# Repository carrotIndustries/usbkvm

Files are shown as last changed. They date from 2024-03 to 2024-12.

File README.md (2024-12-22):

USBKVM
======

You know this? Your home server won't ping anymore and now you gotta 
get a monitor and a keyboard to fix it, but can't find anywhere to put 
them?

Introducing USBKVM, a matchbox-sized keyboard, video monitor and mouse 
that you can use from the comfort of the screen and input devices you 
already have. It's just like a KVM over IP console you may find in a server 
rack, but without the network in between.

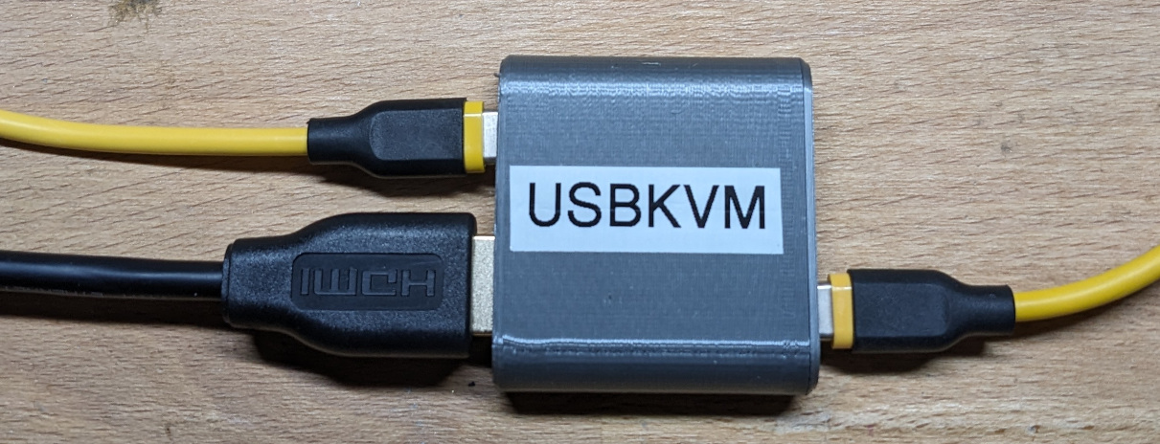
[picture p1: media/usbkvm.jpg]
A grey, obround 3D-printed 5x5 cm box with a white "USBKVM" label on it. A black HDMI cable an a yellow USB Type-C cable are connected on the left side. Another yellow USB Type-C cable is plugged into the right side.


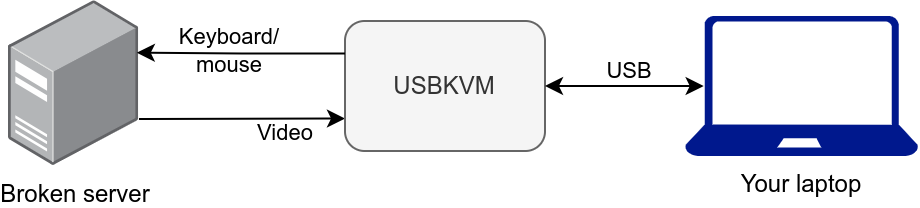
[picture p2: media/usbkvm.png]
Diagram showing a server connected to a laptop using USBKVM


# Quickstart

So you just your got your hands on a USBKVM and want to use it? See the app's [README](app/README.md) for how to install the client app.

# Hardware (USBKVM)

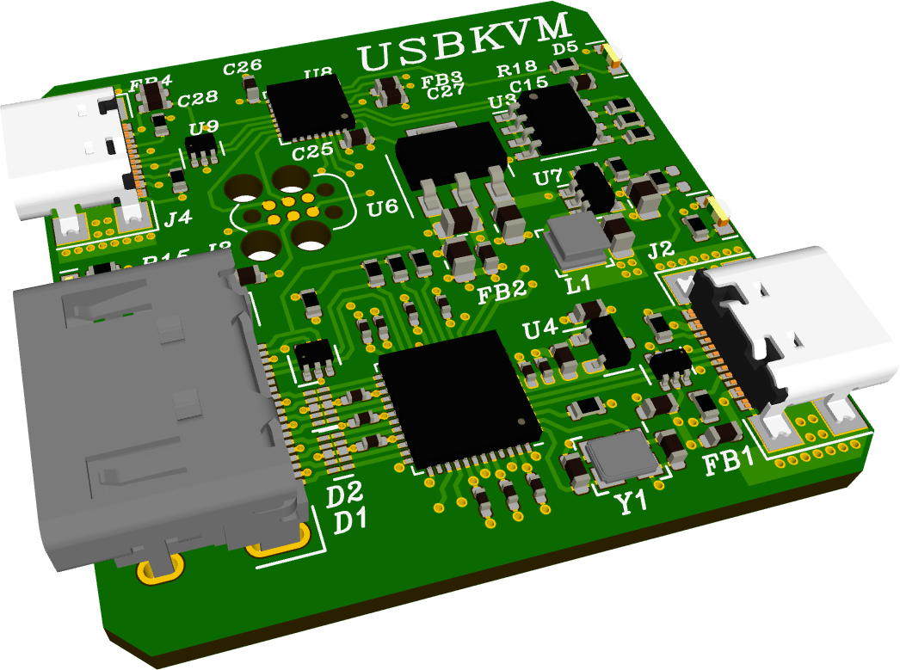
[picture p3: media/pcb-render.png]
3D rendering of a green PCA with an HDMI and a USB Type-C connector on the left edge. On the board itself, there are two QFN ICs as well as a variety of other components. On the right edge, there's another USB Type-C connector. USBKVM is silkscreend in the top right corner.


USBKVM is built around the MS2109 HDMI to USB capture IC that's found 
on virtually all cheap USB 2.0 HDMI capture sticks. It's not stocked by 
any of the usual distributors, I got mine from 
[klayers.net](https://www.klayers.net/product/ms2109/). They came with 
the [marking lasered 
off](https://chaos.social/@karotte/111456303962668464), which made me a bit suspicious that I've been 
scammed, but they work just like the original. So I either got the real 
deal or a perfect clone.

Turns out that this chip has an I²C controller builtin and people 
[reverse engineered](https://github.com/BertoldVdb/ms-tools/) to the 
point that it can be used to communicate with arbitrary I²C devices.

This I²C side channel is used to talk to an STM32F042 MCU that emulates 
USB keyboard and mouse.

Apart from these two chips, there's not much else on the board other 
than some voltage regulators, ESD protection diodes and an I²C EEPROM 
that holds configuration data for the MS2109.

The differential pairs for HDMI and USB are designed for JLCPCB's 7628 
stackup.

As usual, this board is made with [Horizon 
EDA](https://horizon-eda.org/). [Schematics](hw/usbkvm/output/schematic.pdf)

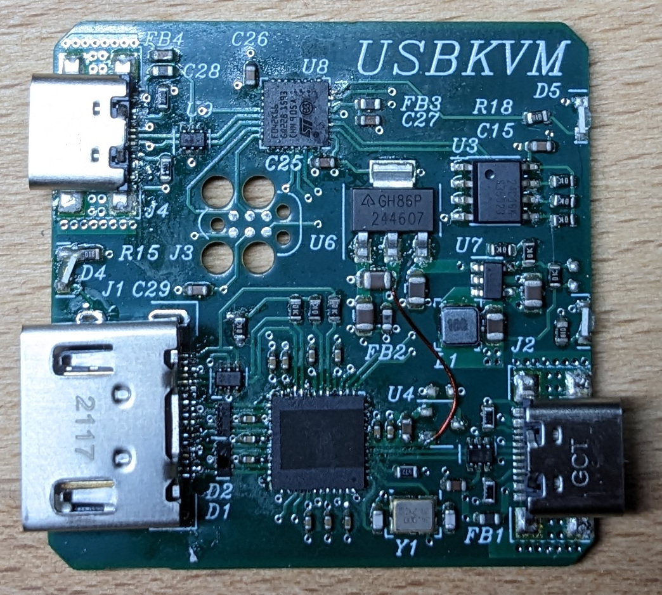
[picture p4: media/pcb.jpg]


The modwire is there because I forgot to order the voltage regulator 
for the 3.3V USB supply.

# Hardware (USBKVM Pro)

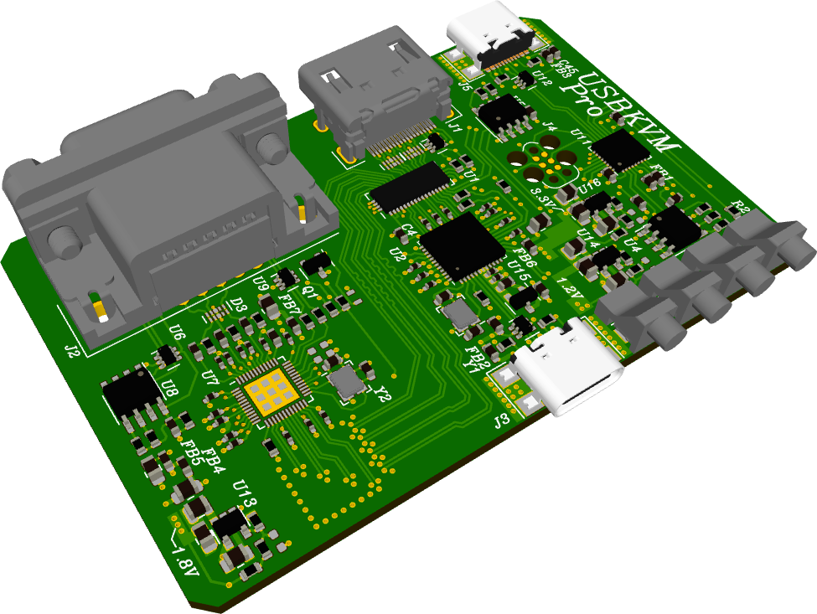
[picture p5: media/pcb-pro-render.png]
3D rendering of a green PCA with a VGA, HDMI and a USB Type-C connector on the left edge. On the board itself, there are thre QFN ICs as well as a variety of other components. On the right edge, there's another USB Type-C connector and four light pipes. USBKVM Pro is silkscreend in the top corner.


USBKVM Pro adds a VGA input since many servers still only provide VGA
video output. To accomplish this, the board includes the MS9288C VGA to 
HDMI converter and an HDMI mux to switch between HDMI and VGA input. 
Same as the MS2109, the MS9288C is available from 
[klayers.net](https://www.klayers.net/product/ms9288c/). The board has 
provision for connecting an I²C EEPROM to it, but so far I haven't 
found any documentation on how to make use of it. Anyhow, the chip 
works just fine without the EEPROM.

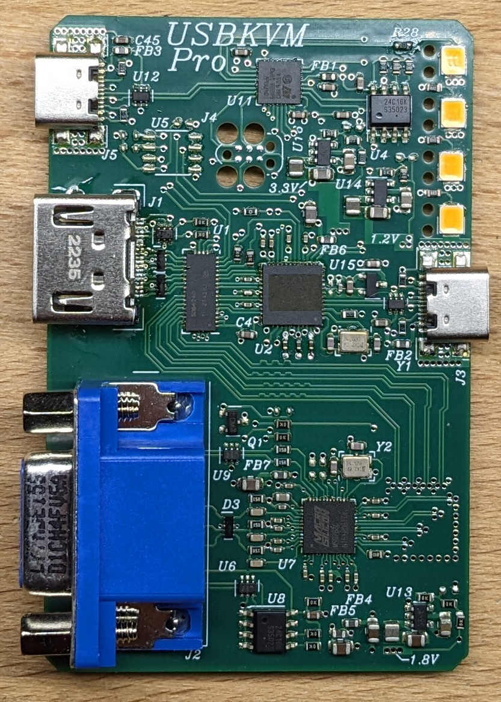
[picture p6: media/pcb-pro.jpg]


For automatically switching between HDMI and VGA input, the MCU senses 
the +5V applied to the VGA connector with an N-channel MOSFET. It's not 
directly connected to the MCU since it could reverse-power the MCU if 
host power isn't connected. For the same reason the I²C lines for the 
EDID EEPROM aren't connected to the MCU either.

USBKVM Pro uses warm white status LEDs since that's an indicator LED 
color I'd like to see more often among the sea of cold white and 
colored LEDs. Unfortunately though there are no decent warm white 
indicator LEDs, much less side view variants. So I went with LEDs 
intended for lighting applications running at much lower current and 
light pipes.

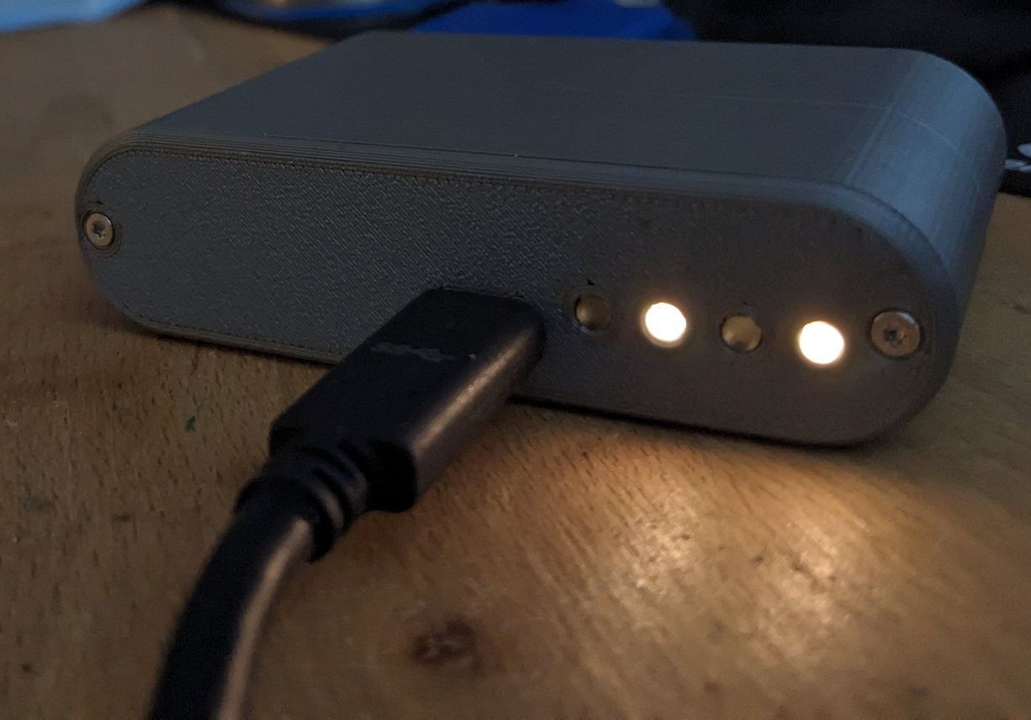
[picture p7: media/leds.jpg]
Warm white status LEDs reflecting on a wooden surface


# Programming

To be recognized by the client app and show color bars rather than a 
black screen for no input signal, the EEPROM attached to the MS2109 
needs to be programmed. This is done with the `cli` included in 
`ms-tools`: `./cli write-file EEPROM 0 progdata/ms2109.bin`. The EEPROM 
content is based on the one of a capture stick, modified with 
the "MS21XX&91XXDownloadTool_1.7.0" to set the device string to "USBKVM". 

For the Pro variant, there's also the VGA EDID EEPROM that requires 
programming. I cobbled together its contents by combining the EDID 
data from an LCD monitor with the one from the MS2109 using the [AW 
EDID 
Editor](https://www.analogway.com/emea/products/software-tools/aw-edid-editor/).
It's intended to be programmed using the VGA connector. To do so, load 
the `i2c-dev` kernel module and use the [converter 
script](progdata/convert-edid.py) to convert the EDID EEPROM 
[contents](progdata/edid.bin)
to a set of `i2ctransfer` commands. You probably need to adjust the I²C 
bus number to the right one for your system.

Apart from the firmware, the MCU needs the BOOT_SEL option bit cleared 
so that it can jump to the ROM bootloader. Unfortunately, openocd 
doesn't support this bit(?), so it has to be modified using the 
STM32Cube Programmer or via DFU.

# Software

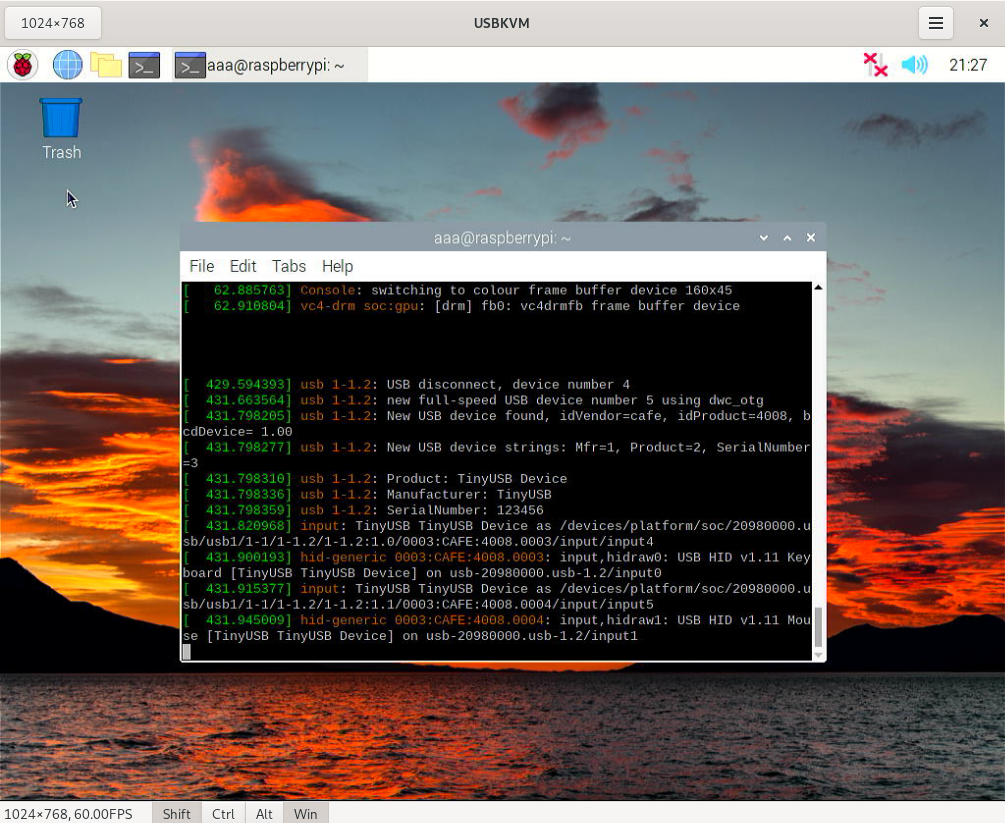
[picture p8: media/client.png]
The default Raspberry Pi OS desktop with a terminal window showing some dmesg output.


Conceptually, the client is pretty simple as it only has to do these 
two jobs:
 1. Display the captured video feed. The MS2109 implements the USB 
 video device class, just like a webcam.
 2. Send keyboard and mouse input the the MCU via the aforementioned I²C 
 interface

To get some video on the screen quickly, the client started out as a 
GStreamer Gtk example, first part done!

The second part however 
required some more work as the code that makes use of the MS2109's I²C 
interface is written in Go. After realizing that it's a surprisingly 
substantial amount code, I quickly scrapped the idea of reimplementing 
it in C++ and instead figured out how to compile it as a static library 
that I can integrate into my C++ project.

The protocol layer used for communicating with the MCU firmware is defined in 
a header file that's both included by the client an the firmware. Some 
care has to be taken to get the same struct packing on both platforms.

To keep the firmware simple, the client has to send USB HID scan codes, 
so it has to generate them from the key codes it receives from Gtk.
Not wanting to reinvent the wheel, I looked into the 
sources of software that has has to accomplish a similar task, in 
particular the [SPICE Gtk 
client](https://gitlab.freedesktop.org/spice/spice-gtk), and discovered 
the [keycodemap](https://gitlab.com/keycodemap/keycodemapdb) project. 
It provides a mapping table from the X11 keycodes used by Gtk to HID 
scancodes among some other codes used by different platforms.

Since I was too lazy to figure out how to properly capture the mouse to 
emit relative movements, USBKVM emulates an absolute pointing device. While this works perfectly 
on Windows and Linux, it's completely broken in less sophisticated 
environments such as UEFI setup utilities or option ROMs.

See the app's [README](app/README.md) for how to build it.

# Firmware

The firmware uses the excellent USB stack 
[tinyusb](https://github.com/hathach/tinyusb) to emulate the 
aforementioned absolute pointing devices as well as a standard USB HID 
keyboard. After having used the USB device stack included in the STM32 
HAL in some previous projects, I can't recommend tinyusb enough. It's 
really good as far as anything involving USB goes.

On the other end, it implements an I²C peripheral to receive commands 
from the MS2109. After some fiddling, I got it to work reliably 
without clock stretching since I don't think the MS2109 supports that. 
One side-effect of that is that the first byte the MCU has to send in a 
read transaction has to be loaded into the transmit data register even 
before the address is received since the time between the SCL edge that 
latches the last address bit and the first edge that clocks out the 
first data bye isn't long enough to prepare the data to be sent.

USBKVM and USBKVM Pro hardware variants are supported by one single 
firmware image. To tell them apart, pin PB8 is grounded on USBKVM Pro 
and floating on USBKVM.

## Firmware updates

TL;DR: Don't worry about it, the client app automatically does the right thing.

The first 8k of the 32kByte flash are reserved for the bootloader that can re-program the application image as directed via the I²C interface. The application image is prefixed by a header that contains its length and CRC checksum that the bootloader verifies before jumping to it. To make USBKVM brick-proof under normal usage, the bootloader doesn't immediately jump to the application on its own, but has to be told so by the client app. That way even an application image that passes the CRC check, but can't jump back to the bootloader doesn't result in a bricked USBKVM.

## Development

There are two firmware projects in the `fw/boot` and `fw/usbkvm` subdirectories. They share some code in `fw/common/`. Building them requires the usual arm-none-eabi toolchain, GNU make and python.

# Case

As usual, the case is of the 3D-printed kind. It consists of the 
obround main housing and a lid to close it up. The lid attaches with two M2 screws 
that go into nuts located in the main housing.

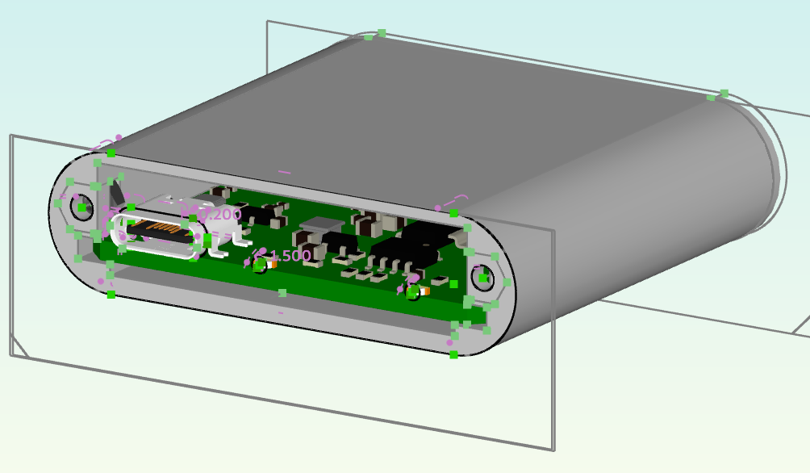
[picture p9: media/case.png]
Dune 3D screenshot of the case without the lid and some constraints visible.


The case was designed in [Dune 3D](https://dune3d.org/).

# Frequently asked questions

## Why doesn't this already exist?

Good question, given that at least
[three](https://news.ycombinator.com/item?id=39471860) 
[people](https://digipres.club/@foone/111948980229300662)
[independently](https://ioc.exchange/@azonenberg/110849751773610561)
asked the same thing. All of the key components 
are available off the shelf and USBKVM wasn't exactly hard to put 
together, 
so I guess it's mostly a question of time until someone else would have 
figured it out as well.

While writing this README, I stumbled upon 
[openinterface.com](https://openterface.com/) which appears to be 
pretty much the same thing as USBKVM. Zooming into [one of their PCB 
photos](https://twitter.com/TechxArtisan/status/1755577720568750462), 
they're also using the MS2109, what a coincidence! Looking at their 
subreddit they just went live less than two months ago.

## Why is this using such an obscure chip from a Chinese vendor?

I thought about how USBKVM would look like if I had to make it from 
parts I could get from Digikey. The best solution I could come up with 
would be using
a large MCU with camera input and High-Speed USB and then somehow 
connecting an HDMI to parallel RGB 
converter to its camera interface. While this could also have 
eliminated the MCU used for HID emulation, it's much more complex and 
expensive than the single QFN-48 IC that is the MS2109.

## How can I get one?

I have no plans to commercially offer USBKVM since I don't 
want to deal with the hurdles of manufacturing and selling hardware 
products.

If you're in the business of manufacturing and selling hardware, feel 
free to take the design files and turn USBKVM into a product people can 
buy! Just keep in mind that the firmware and client app are under GPL 
when making modifications to it.

## What platforms does the client run on?

Right now, the client app builds and runs on Linux. Windows support is 
experimental.

## Are there plans for clients for other platforms?

Right now, no. You're more than welcome to implement a client for your 
favourite platform based on the client included in this repo.

# Future improvements

While there's not much to improve on the hardware as it is right now, 
the client app still has a lot of room for improvement.

 - Make sure that it handles non-US keyboard layouts on both ends
 - Relative mouse emulation, requires firmware support
 - Screen recording, should be easy to add to the GStreamer pipeline
 - Instant replay to show screen content that just scrolled by
 - Key macros for repeatedly pressing keys
 - OCR for copying text from the video feed
 - Hardware mod: Wire up CEC from the HDMI connector to the MCU

# Licenses

 - Firmware and client: GPLv3
 - Hardware and Case: CERN Open Hardware Licence Version 2 - Permissive

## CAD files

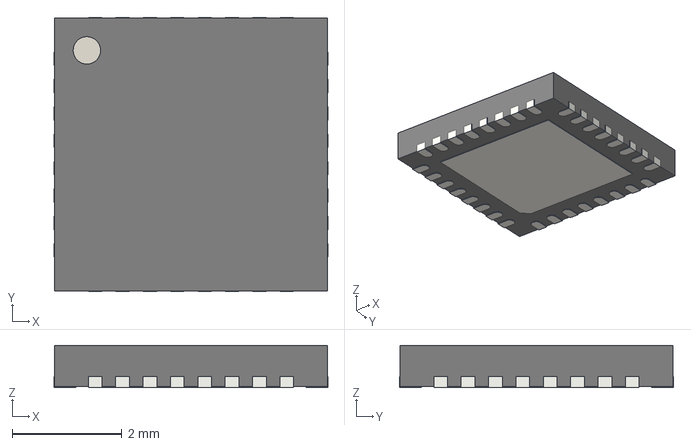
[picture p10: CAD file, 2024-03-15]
hw/usbkvm-pro/pool/3d_models/cache/6d752bc3-29b3-45df-8cf2-1e3aacefbcc6/3d_models/ic/qfn/QFN-32-1EP_5x5mm_P0.5mm.step
5.00 x 5.00 x 0.77 mm

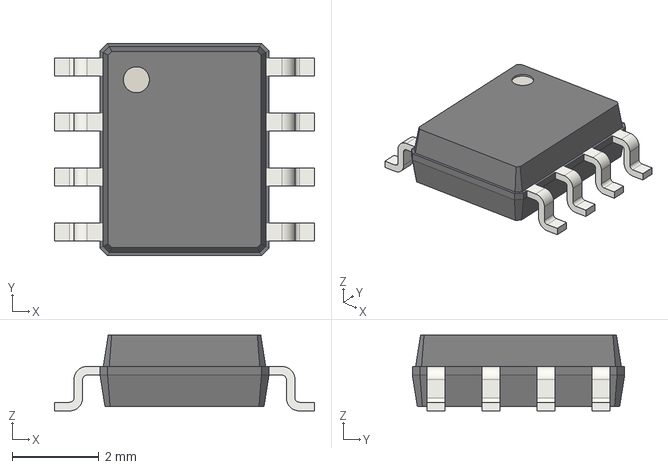
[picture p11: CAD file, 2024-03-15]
hw/usbkvm-pro/pool/3d_models/cache/6d752bc3-29b3-45df-8cf2-1e3aacefbcc6/3d_models/ic/so/SOIC-8_3.9x4.9mm_P1.27mm.step
6.00 x 4.90 x 1.75 mm

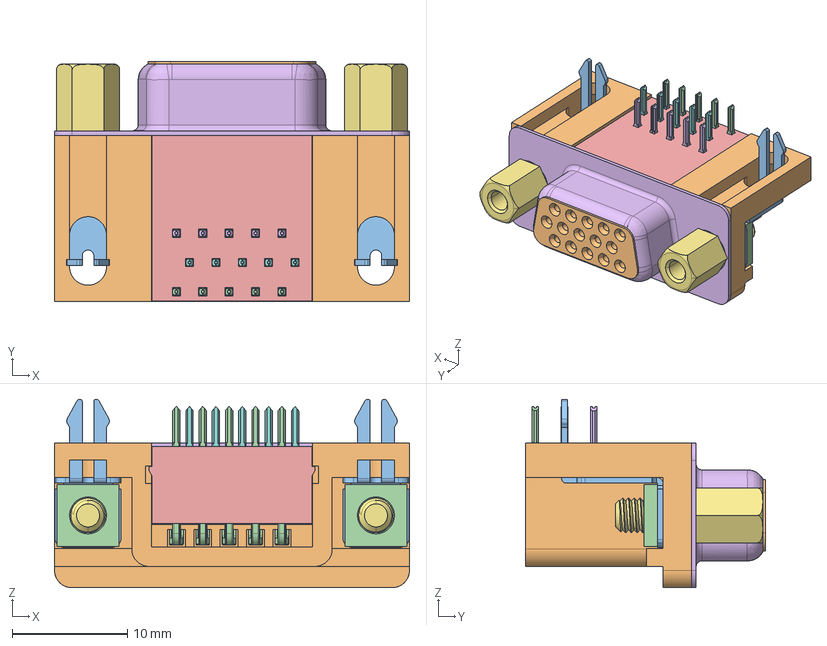
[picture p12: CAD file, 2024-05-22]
hw/usbkvm-pro/pool/3d_models/cache/6d752bc3-29b3-45df-8cf2-1e3aacefbcc6/3d_models/local/connectors/d-sub/L77HDE15SD1CH4FVGA--3DModel-STEP-533217.STEP
30.8 x 20.8 x 16.4 mm
D112-H15S_79
ZZ_11 x 2
MM_3 x 2
MANIFOLD_SOLID_BREP_13339 x 5
MANIFOLD_SOLID_BREP_16179 x 5
MANIFOLD_SOLID_BREP_18054
MANIFOLD_SOLID_BREP_20824
MANIFOLD_SOLID_BREP_22635
MANIFOLD_SOLID_BREP_25405
MANIFOLD_SOLID_BREP_27216
MANIFOLD_SOLID_BREP_29986
MANIFOLD_SOLID_BREP_31797
MANIFOLD_SOLID_BREP_34567
MANIFOLD_SOLID_BREP_37337
MANIFOLD_SOLID_BREP_39100
MANIFOLD_SOLID_BREP_40938 x 5
MANIFOLD_SOLID_BREP_43779 x 5
CC_25
H15S-SHEL_1
MM-2_1 x 2

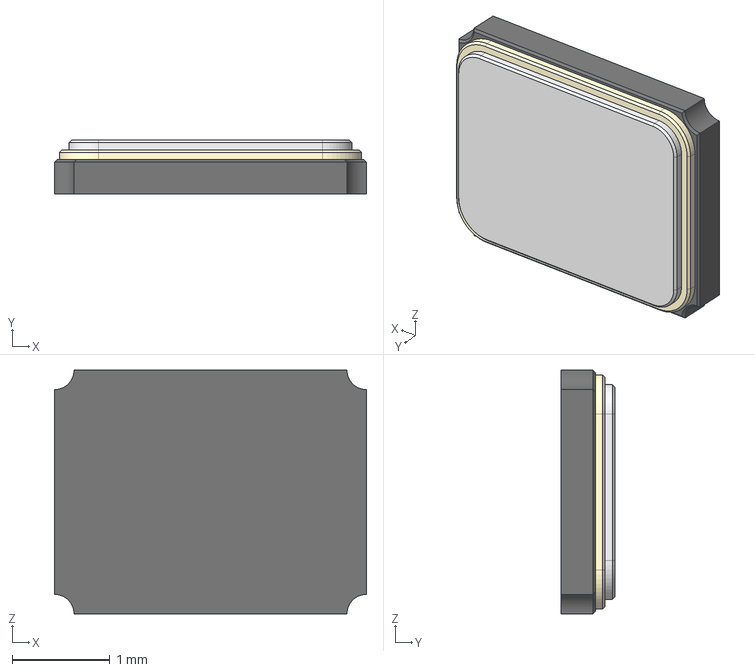
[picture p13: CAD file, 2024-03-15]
hw/usbkvm-pro/pool/3d_models/cache/6d752bc3-29b3-45df-8cf2-1e3aacefbcc6/3d_models/local/crystal/NX3225SA v2.step
3.20 x 0.55 x 2.50 mm

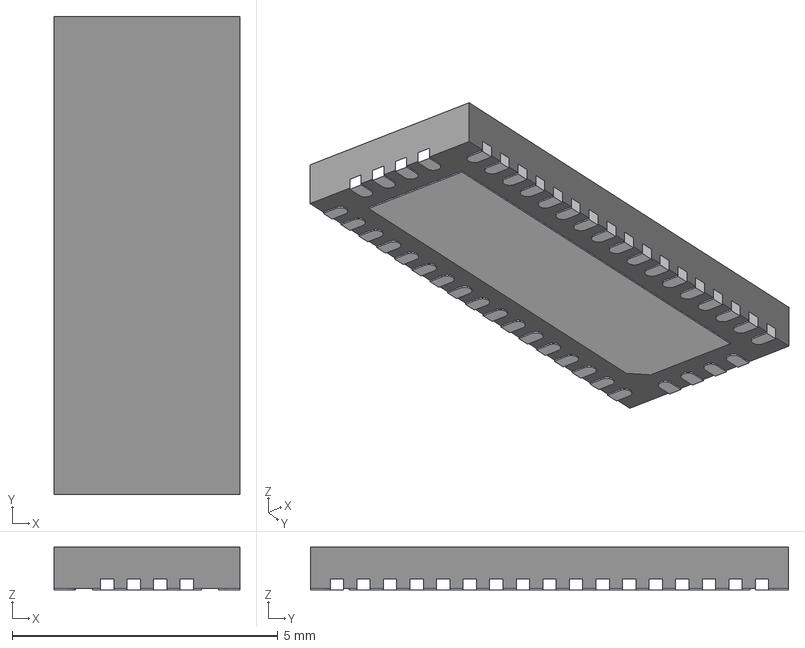
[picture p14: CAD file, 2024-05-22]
hw/usbkvm-pro/pool/3d_models/cache/6d752bc3-29b3-45df-8cf2-1e3aacefbcc6/3d_models/local/ic/ti/RUA0042A.stp
3.50 x 9.00 x 0.8 mm
FRAME

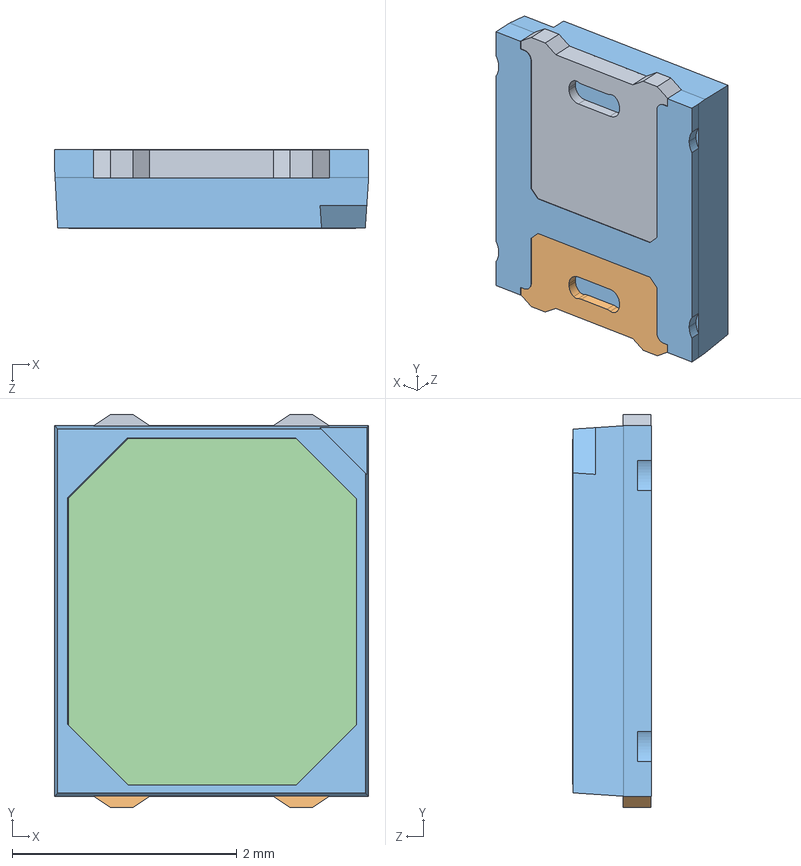
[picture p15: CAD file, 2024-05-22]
hw/usbkvm-pro/pool/3d_models/cache/6d752bc3-29b3-45df-8cf2-1e3aacefbcc6/3d_models/local/led/J Series 2835.STEP
2.80 x 3.50 x 0.706 mm
_____.STEP
_____-0.STEP
____.STEP

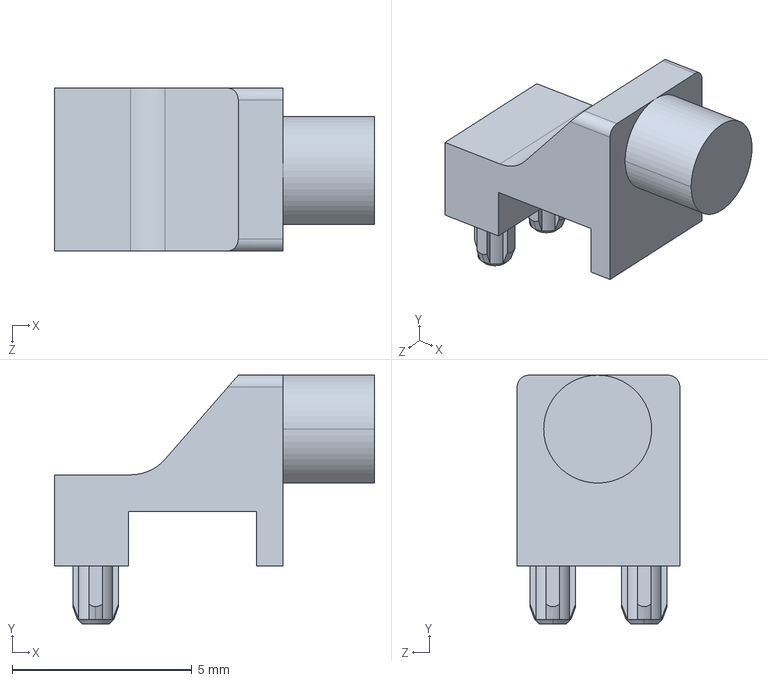
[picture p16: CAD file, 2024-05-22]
hw/usbkvm-pro/pool/3d_models/cache/6d752bc3-29b3-45df-8cf2-1e3aacefbcc6/3d_models/local/light-pipe/BIVAR__INC_SLP3-150-100-F.step
8.89 x 6.91 x 4.52 mm

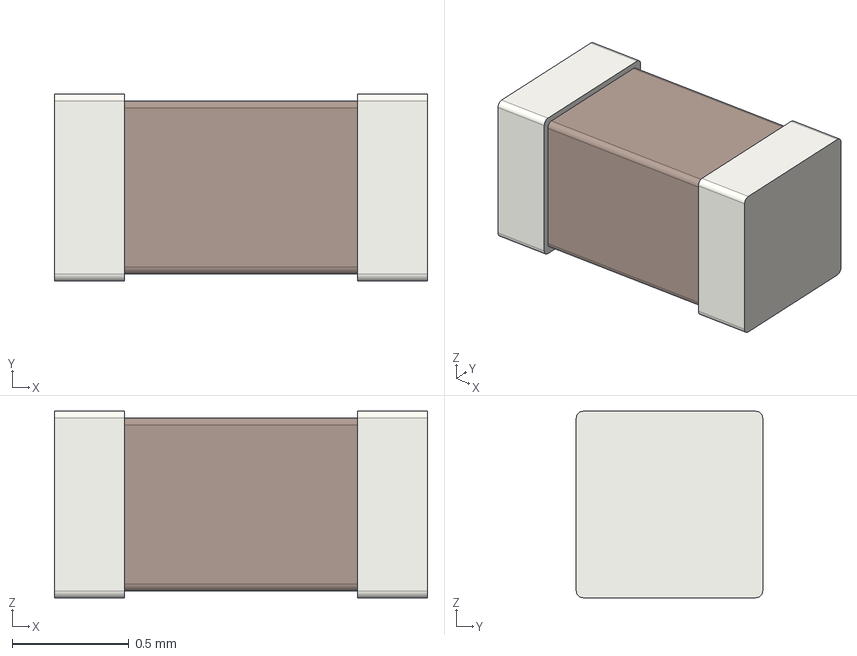
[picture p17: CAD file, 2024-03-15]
hw/usbkvm-pro/pool/3d_models/cache/6d752bc3-29b3-45df-8cf2-1e3aacefbcc6/3d_models/passive/capacitor/C_0603_1608Metric.step
1.60 x 0.8 x 0.8 mm

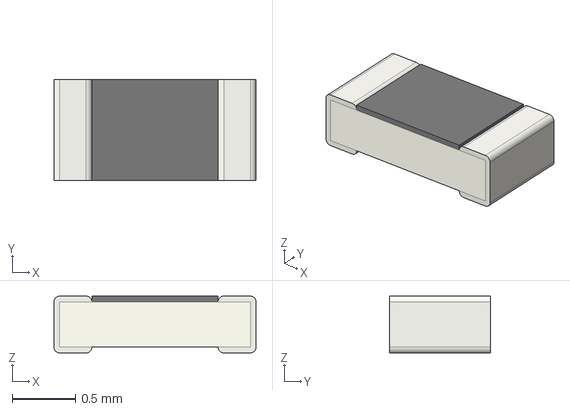
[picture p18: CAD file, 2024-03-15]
hw/usbkvm-pro/pool/3d_models/cache/6d752bc3-29b3-45df-8cf2-1e3aacefbcc6/3d_models/passive/resistor/R_0603_1608Metric.step
1.60 x 0.8 x 0.45 mm

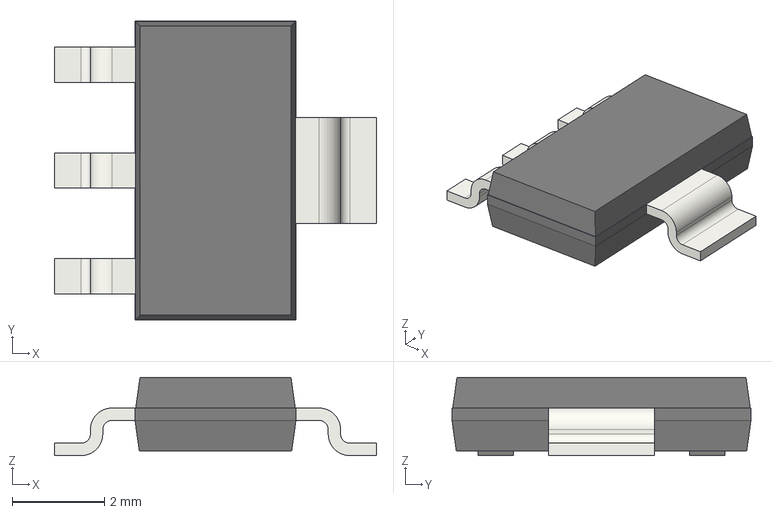
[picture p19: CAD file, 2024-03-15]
hw/usbkvm/pool/3d_models/cache/6d752bc3-29b3-45df-8cf2-1e3aacefbcc6/3d_models/ic/so/SOT-223.step
7.00 x 6.50 x 1.70 mm

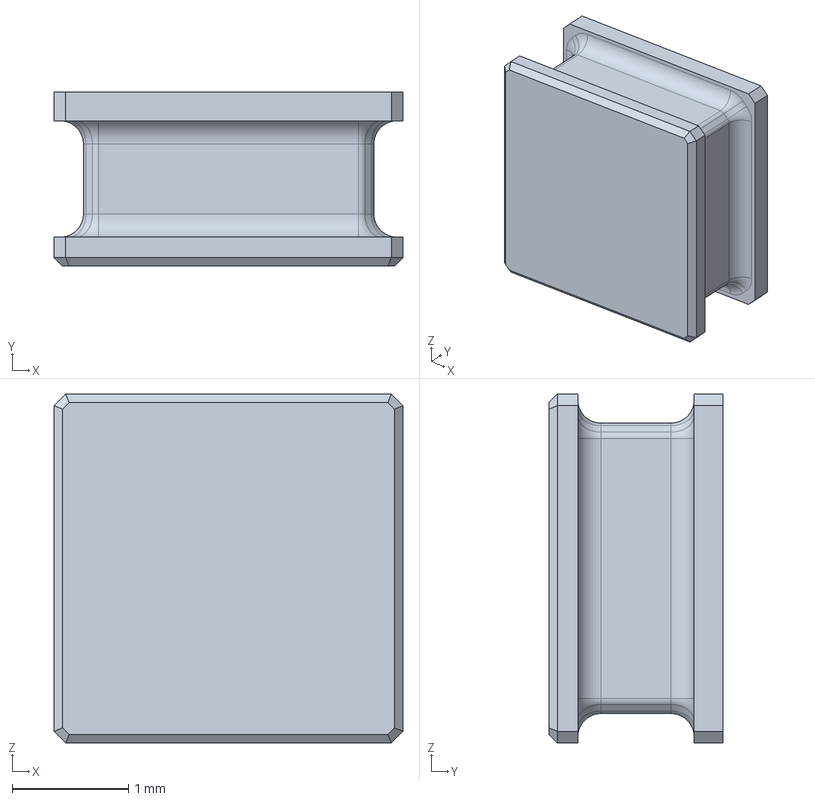
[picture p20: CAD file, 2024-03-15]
hw/usbkvm/pool/3d_models/cache/6d752bc3-29b3-45df-8cf2-1e3aacefbcc6/3d_models/local/inductors/Bourns-SRN3015.step
3.00 x 1.50 x 3.00 mm

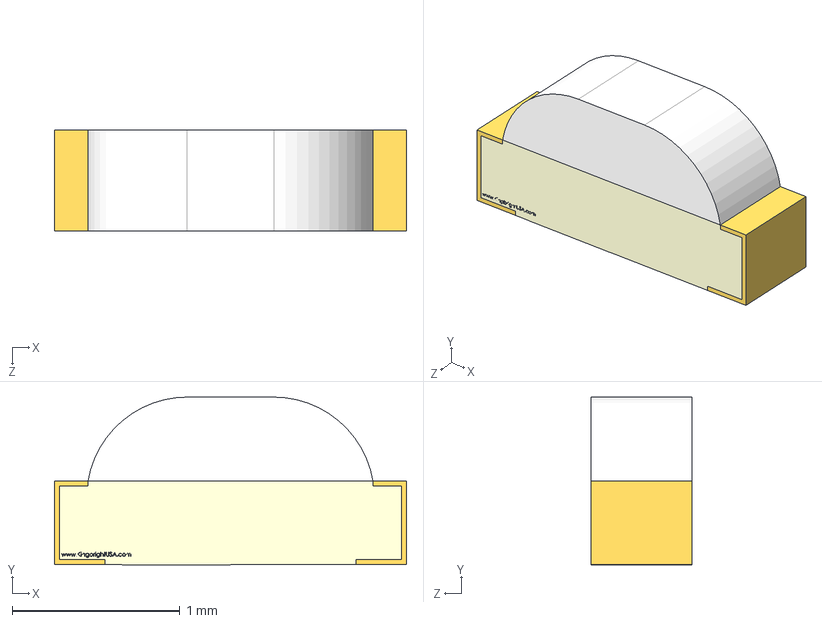
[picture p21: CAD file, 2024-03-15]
hw/usbkvm/pool/3d_models/cache/6d752bc3-29b3-45df-8cf2-1e3aacefbcc6/3d_models/local/led/APA2107.STEP
2.10 x 1.00 x 0.6 mm

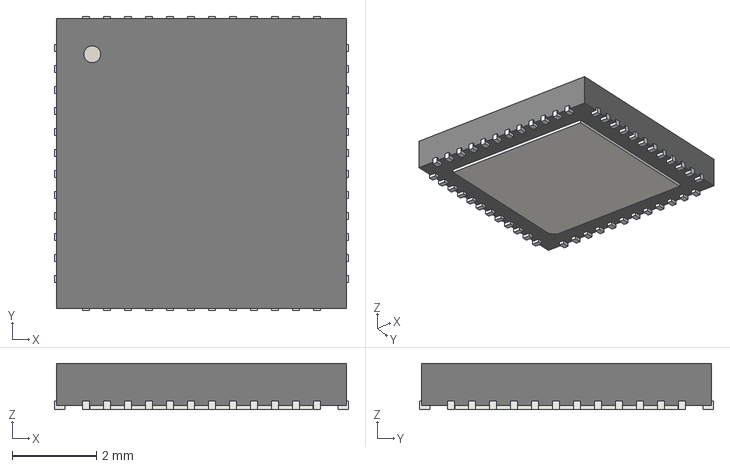
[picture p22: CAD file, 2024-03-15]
hw/usbkvm-pro/pool/3d_models/cache/6d752bc3-29b3-45df-8cf2-1e3aacefbcc6/3d_models/ic/qfn/QFN-48-1EP_7x7mm_P0.5mm_EP5.3x5.3mm.step
7.00 x 7.00 x 1.10 mm

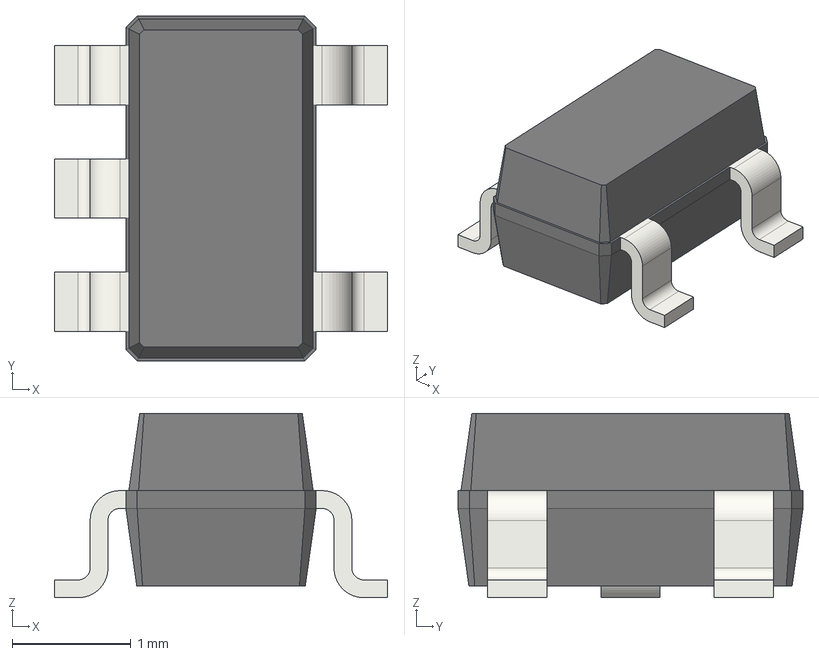
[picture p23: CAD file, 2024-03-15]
hw/usbkvm-pro/pool/3d_models/cache/6d752bc3-29b3-45df-8cf2-1e3aacefbcc6/3d_models/ic/so/SOT-23-5.step
2.80 x 2.90 x 1.55 mm

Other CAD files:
hw/usbkvm-pro/pool/3d_models/cache/6d752bc3-29b3-45df-8cf2-1e3aacefbcc6/3d_models/passive/capacitor/C_0402_1005Metric.step
hw/usbkvm-pro/pool/3d_models/cache/6d752bc3-29b3-45df-8cf2-1e3aacefbcc6/3d_models/ic/so/SOT-23.step
hw/usbkvm-pro/pool/3d_models/cache/6d752bc3-29b3-45df-8cf2-1e3aacefbcc6/3d_models/passive/capacitor/C_0805_2012Metric.step
hw/usbkvm-pro/pool/3d_models/cache/6d752bc3-29b3-45df-8cf2-1e3aacefbcc6/3d_models/ic/so/SOT-363_SC-70-6.step
hw/usbkvm-pro/pool/3d_models/cache/6d752bc3-29b3-45df-8cf2-1e3aacefbcc6/3d_models/local/connectors/hdmi/2086581051.stp
mech/90592A075_Steel Hex Nut.step

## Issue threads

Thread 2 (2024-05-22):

24Cxx EEPROM size and contents

G33KatWork, 2024-05-22:
Hi,

I want to build my own USBKVM. The BOM isn't clear on how big the 24Cxx EEPROM is supposed to be as the metadata in the Horizon project just says "24Cxx SOIC8" and not an exact part number. The part number isn't exactly readable either on the PCB image due to JPEG artifacts.

Also I guess it contains the firmware for the MS2109 that I need to dump from a USB/HDMI adapter and then write into the EEPROM? Or does the device work with just the ROM code as well?

carrotIndustries, 2024-05-22:
Will update the schematics in the coming days and add some flashing instructions.

It's a 16kBit eeprom and you need to program it with that file https://github.com/carrotIndustries/usbkvm/blob/main/hw/usbkvm/eep-usbkvm.bin using the cli from ms-tools: `cli  write-file EEPROM 0 eep-usbkvm.bin`

It's the EEPROM contents from the capture stick I ordered for testing, modified with the "MS21XX&91XXDownloadTool_1.7.0" to set the device string to "USBKVM". With the EEPROM contents I have it also shows color bars rather than a black screen when there's no input signal.

There's still a lot to be reverse-engineered about the MS2109.

G33KatWork, 2024-05-22:
Thanks!

I totally missed the bin file when looking around.

G33KatWork, 2024-06-02:
Okay, next question: Q1 in the USBKVM pro is again only a generic N-Channel MOSFET instead of an explicit part. Which one is it exactly?

carrotIndustries, 2024-06-02:
> Which one is it exactly?

2N7002, anything comparable will do.

> edit: And I assume the three (!) I2C EEPROM on the pro are all the same 16KBit EEPROMs?

The EEPROM for the MS9288C isn't required as I haven't found any info about what to put in it and the chip works fine without it.

For the VGA EDID eeprom, a 2kBit EEPROM would work as well, but I'm using a 16k one to keep the BOM shorter.

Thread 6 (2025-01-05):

mac OS Support

carrotIndustries, 2025-01-05:
So far, the USBKVM app only works on Linux and Windows. For mac OS support, at least these things need to be fixed:
 - Use the appropriate gstreamer source element
 - Figure out how to get the bus info from the video device
 - Figure out how to get the bus info from the HID device

The bus info is required to match up video and HID device.

JanKoppe, 2025-01-07:
Happy to play beta tester.

carrotIndustries, 2025-01-07:
A good start would be the output of `gst-device-monitor-1.0 -i Video/Source`  with a USBKVM attached.

iiidefix, 2025-01-13:
output of `gst-device-monitor-1.0 -i Video/Source` on macOS Sequoia 15.2 with gstreamer from Homebrew:
```
Device found:

        name  : USBKVM
        class : Video/Source
        caps  : video/x-raw(memory:GLMemory), width=1920, height=1080, format={ (string)UYVY, (string)YUY2 }, framerate={ (fraction)10/1, (fraction)20/1, (fraction)25/1, (fraction)3000003/100000, (fraction)750003/12500, (fraction)5/1 }, texture-target=rectangle
                video/x-raw(memory:GLMemory), width=1600, height=1200, format={ (string)UYVY, (string)YUY2 }, framerate={ (fraction)10/1, (fraction)20/1, (fraction)25/1, (fraction)3000003/100000, (fraction)750003/12500, (fraction)5/1 }, texture-target=rectangle
                video/x-raw(memory:GLMemory), width=1360, height=768, format={ (string)UYVY, (string)YUY2 }, framerate={ (fraction)10/1, (fraction)20/1, (fraction)25/1, (fraction)3000003/100000, (fraction)750003/12500, (fraction)8/1 }, texture-target=rectangle
                video/x-raw(memory:GLMemory), width=1280, height=1024, format={ (string)UYVY, (string)YUY2 }, framerate={ (fraction)10/1, (fraction)20/1, (fraction)25/1, (fraction)3000003/100000, (fraction)750003/12500, (fraction)8/1 }, texture-target=rectangle
                video/x-raw(memory:GLMemory), width=1280, height=960, format={ (string)UYVY, (string)YUY2 }, framerate={ (fraction)10/1, (fraction)20/1, (fraction)25/1, (fraction)3000003/100000, (fraction)750003/12500, (fraction)8/1 }, texture-target=rectangle
                video/x-raw(memory:GLMemory), width=1280, height=720, format={ (string)UYVY, (string)YUY2 }, framerate={ (fraction)20/1, (fraction)3000003/100000, (fraction)50/1, (fraction)750003/12500, (fraction)10/1 }, texture-target=rectangle
                video/x-raw(memory:GLMemory), width=1024, height=768, format={ (string)UYVY, (string)YUY2 }, framerate={ (fraction)20/1, (fraction)3000003/100000, (fraction)50/1, (fraction)750003/12500, (fraction)10/1 }, texture-target=rectangle
                video/x-raw(memory:GLMemory), width=800, height=600, format={ (string)UYVY, (string)YUY2 }, framerate={ (fraction)3000003/100000, (fraction)50/1, (fraction)750003/12500, (fraction)5/1, (fraction)10/1, (fraction)20/1 }, texture-target=rectangle
                video/x-raw(memory:GLMemory), width=720, height=576, format={ (string)UYVY, (string)YUY2 }, framerate={ (fraction)3000003/100000, (fraction)50/1, (fraction)750003/12500, (fraction)5/1, (fraction)10/1, (fraction)20/1, (fraction)25/1 }, texture-target=rectangle
                video/x-raw(memory:GLMemory), width=720, height=480, format={ (string)UYVY, (string)YUY2 }, framerate={ (fraction)5/1, (fraction)10/1, (fraction)20/1, (fraction)3000003/100000, (fraction)50/1, (fraction)750003/12500 }, texture-target=rectangle
                video/x-raw(memory:GLMemory), width=640, height=480, format={ (string)UYVY, (string)YUY2 }, framerate={ (fraction)5/1, (fraction)10/1, (fraction)20/1, (fraction)3000003/100000, (fraction)50/1, (fraction)750003/12500 }, texture-target=rectangle
                video/x-raw, width=1920, height=1080, format={ (string)UYVY, (string)YUY2, (string)NV12, (string)ARGB, (string)BGRA }, framerate={ (fraction)10/1, (fraction)20/1, (fraction)25/1, (fraction)3000003/100000, (fraction)750003/12500, (fraction)5/1 }
                video/x-raw, width=1600, height=1200, format={ (string)UYVY, (string)YUY2, (string)NV12, (string)ARGB, (string)BGRA }, framerate={ (fraction)10/1, (fraction)20/1, (fraction)25/1, (fraction)3000003/100000, (fraction)750003/12500, (fraction)5/1 }
                video/x-raw, width=1360, height=768, format={ (string)UYVY, (string)YUY2, (string)NV12, (string)ARGB, (string)BGRA }, framerate={ (fraction)10/1, (fraction)20/1, (fraction)25/1, (fraction)3000003/100000, (fraction)750003/12500, (fraction)8/1 }
                video/x-raw, width=1280, height=1024, format={ (string)UYVY, (string)YUY2, (string)NV12, (string)ARGB, (string)BGRA }, framerate={ (fraction)10/1, (fraction)20/1, (fraction)25/1, (fraction)3000003/100000, (fraction)750003/12500, (fraction)8/1 }
                video/x-raw, width=1280, height=960, format={ (string)UYVY, (string)YUY2, (string)NV12, (string)ARGB, (string)BGRA }, framerate={ (fraction)10/1, (fraction)20/1, (fraction)25/1, (fraction)3000003/100000, (fraction)750003/12500, (fraction)8/1 }
                video/x-raw, width=1280, height=720, format={ (string)UYVY, (string)YUY2, (string)NV12, (string)ARGB, (string)BGRA }, framerate={ (fraction)20/1, (fraction)3000003/100000, (fraction)50/1, (fraction)750003/12500, (fraction)10/1 }
                video/x-raw, width=1024, height=768, format={ (string)UYVY, (string)YUY2, (string)NV12, (string)ARGB, (string)BGRA }, framerate={ (fraction)20/1, (fraction)3000003/100000, (fraction)50/1, (fraction)750003/12500, (fraction)10/1 }
                video/x-raw, width=800, height=600, format={ (string)UYVY, (string)YUY2, (string)NV12, (string)ARGB, (string)BGRA }, framerate={ (fraction)3000003/100000, (fraction)50/1, (fraction)750003/12500, (fraction)5/1, (fraction)10/1, (fraction)20/1 }
                video/x-raw, width=720, height=576, format={ (string)UYVY, (string)YUY2, (string)NV12, (string)ARGB, (string)BGRA }, framerate={ (fraction)3000003/100000, (fraction)50/1, (fraction)750003/12500, (fraction)5/1, (fraction)10/1, (fraction)20/1, (fraction)25/1 }
                video/x-raw, width=720, height=480, format={ (string)UYVY, (string)YUY2, (string)NV12, (string)ARGB, (string)BGRA }, framerate={ (fraction)5/1, (fraction)10/1, (fraction)20/1, (fraction)3000003/100000, (fraction)50/1, (fraction)750003/12500 }
                video/x-raw, width=640, height=480, format={ (string)UYVY, (string)YUY2, (string)NV12, (string)ARGB, (string)BGRA }, framerate={ (fraction)5/1, (fraction)10/1, (fraction)20/1, (fraction)3000003/100000, (fraction)50/1, (fraction)750003/12500 }
        properties:
                device.api = avf
                avf.unique_id = 0x100000534d2109
                avf.model_id = UVC Camera VendorID_21325 ProductID_8457
                avf.has_flash = false
                avf.has_torch = false
                avf.manufacturer = MACROSILICON
        gst-launch-1.0 avfvideosrc device-index=0 ! ...
```

And `gst-device-monitor-1.0 -i Audio/Source` for reference:
```
Device found:

        name  : USB Digital Audio
        class : Audio/Source
        caps  : audio/x-raw, format=F32LE, layout=interleaved, rate=96000, channels=1
                audio/x-raw, format={ (string)F64LE, (string)F64BE, (string)F32LE, (string)F32BE, (string)S32LE, (string)S32BE, (string)U32LE, (string)U32BE, (string)S24_32LE, (string)S24_32BE, (string)U24_32LE, (string)U24_32BE, (string)S24LE, (string)S24BE, (string)U24LE, (string)U24BE, (string)S20LE, (string)S20BE, (string)U20LE, (string)U20BE, (string)S18LE, (string)S18BE, (string)U18LE, (string)U18BE, (string)S16LE, (string)S16BE, (string)U16LE, (string)U16BE, (string)S8, (string)U8 }, layout=interleaved, rate=96000, channels=2, channel-mask=0x0000000000000003
                audio/x-raw, format={ (string)F64LE, (string)F64BE, (string)F32LE, (string)F32BE, (string)S32LE, (string)S32BE, (string)U32LE, (string)U32BE, (string)S24_32LE, (string)S24_32BE, (string)U24_32LE, (string)U24_32BE, (string)S24LE, (string)S24BE, (string)U24LE, (string)U24BE, (string)S20LE, (string)S20BE, (string)U20LE, (string)U20BE, (string)S18LE, (string)S18BE, (string)U18LE, (string)U18BE, (string)S16LE, (string)S16BE, (string)U16LE, (string)U16BE, (string)S8, (string)U8 }, layout=interleaved, rate=96000, channels=1
        gst-launch-1.0 osxaudiosrc device=97 ! ...
```

carrotIndustries, 2025-01-13:
Interesting that there's no `image/jpeg` in there. Maybe modern macs are doing jpeg decoding in hardware as part of AVFoundation?

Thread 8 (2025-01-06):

No USBKVM connected

aelth, 2025-01-06:
Hi,

I bought the device on 38c3.

I'm trying to connect to one of my boxes at the client device says _No USBKVM connected_.
I've tried using the Flatpak version (although I don't really like Flatpak) and have built it from source. Tried on two different machines (both clients and servers) just to make sure there is no hardware issue (although client machines are using the same OS - Debian 13 trixie/testing), but it is the same.

Udev rules have been added, here is dmesg output from one of the machines (the other is similar)P:

```
[Jan 6 17:21] usb 3-3.1.4: new high-speed USB device number 6 using xhci_hcd
[  +0.109197] usb 3-3.1.4: New USB device found, idVendor=534d, idProduct=2109, bcdDevice=21.00
[  +0.000007] usb 3-3.1.4: New USB device strings: Mfr=1, Product=2, SerialNumber=0
[  +0.000003] usb 3-3.1.4: Product: USBKVM
[  +0.000002] usb 3-3.1.4: Manufacturer: MACROSILICON
[  +0.056773] hid-generic 0003:534D:2109.0009: hiddev3,hidraw6: USB HID v1.10 Device [MACROSILICON USBKVM] on usb-0000:2d:00.3-3.1.4/input4
[  +0.025511] mc: Linux media interface: v0.10
[  +0.018849] videodev: Linux video capture interface: v2.00
[  +0.004490] usbcore: registered new interface driver snd-usb-audio
[  +0.009487] usb 3-3.1.4: Found UVC 1.00 device USBKVM (534d:2109)
[  +0.002982] usbcore: registered new interface driver uvcvideo
```

Do I need to preprogram the device? I thought it is pre-programmed since I've bought it and not created it. Also, the device is recognized as USBKVM so I guess it is already programmed.

Do you have any ideas what might be the issue?
Thanks

carrotIndustries, 2025-01-06:
Post the output of `gst-device-monitor-1.0 -i Video/Source`. You should find a v4l2 device called "USBKVM" or so. Which version did you try? The recently-released version 0.2. fixes device detection if libcamera is installed.

aelth, 2025-01-06:
No output on both machines (both clients) :(
I'm using Awesome WM, could that be the case?

I've pulled the version from the Flatpak as described on Flathub and downloaded the v0.2.0 source when I was building from source.

carrotIndustries, 2025-01-06:
Then there's something wrong with your gstreamer setup. Do you have any other video devices such as webcams to test?

Do you see any new `/dev/video*` devices after attaching usbkvm? Maybe there's something wrong with the permissions or so.

aelth, 2025-01-06:
Unfortunately I don't have a USB webcam that I can use to check.

However - I managed to make it working on one of the machines! I did some changes on my USB side (I'm using usbguard) and on the TLP side, and it started working. I think it's not permission related, but I'm not sure what exactly is it:( Firmware upgrade was required and the upgrade was successful after 3 tries - connected to my server and I'm able to see the video and use the keyboard.

Unfortunately it still doesn't work on my laptop (machine where it's working is a PC), but it is now confirmed that it is due to my setup (cannot determine what exactly).
Luckily it also works from a Windows VM on that laptop so I can still use it that way.

Thanks for your help!

carrotIndustries, 2025-01-06:
> Unfortunately it still doesn't work on my laptop

So what *are* the permissions on the /dev/video devices?

carrotIndustries, 2025-01-06:
Ok, does it work if you open either of them in VLC or any other webcam app? This should confirm that v4l is working in general.

To test gstreamer, run `gst-launch-1.0 v4l2src device=/dev/video0 ! jpegdec ! videoconvert ! gtksink`

aelth, 2025-01-06:
I can open it in VLC on a machine where it works.
On a machine where it doesn't work, I obviously cannot open it because there is no /dev/video*

Above gstreamer commands returns `WARNING: erroneous pipeline: no element "gtksink"`.
If I remove the `gtksink` parameter, I get the following (note that the KVM is not connected to anything apart from the client -> my other server is in a separate location and I cannot easily bring them together)
```
gst-launch-1.0 v4l2src device=/dev/video0 ! jpegdec ! videoconvert
Setting pipeline to PAUSED ...
Pipeline is live and does not need PREROLL ...
Pipeline is PREROLLED ...
Setting pipeline to PLAYING ...
New clock: GstSystemClock
ERROR: from element /GstPipeline:pipeline0/GstV4l2Src:v4l2src0: Internal data stream error.
Additional debug info:
../libs/gst/base/gstbasesrc.c(3177): gst_base_src_loop (): /GstPipeline:pipeline0/GstV4l2Src:v4l2src0:
streaming stopped, reason not-linked (-1)
Execution ended after 0:00:00.132355864
Setting pipeline to NULL ...
Freeing pipeline ...
```

carrotIndustries, 2025-01-06:
> WARNING: erroneous pipeline: no element "gtksink".

Then you're missing the gstreamer gtk plugin. Make sure to install all dependencies listed in https://github.com/carrotIndustries/usbkvm/tree/main/app#prerequisites

> On a machine where it doesn't work, I obviously cannot open it because there is no /dev/video*

No idea then, did you somehow manage to have a kernel without UVC class support? You mentioned usbguard. Did you try disabling it?

carrotIndustries, 2025-01-07:
Closing since this doesn't appear to be actionable for the USBKVM app.

Closed 2025-01-07.

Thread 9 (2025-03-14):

Segmentation Fault when running on musl

sdomi, 2025-03-14:
compiled from scratch, getting a SIGSEGV:

```
(gdb) r
Starting program: /home/domi/projects/usbkvm/app/build/usbkvm
[New LWP 21127]

Thread 2 "usbkvm" received signal SIGSEGV, Segmentation fault.
[Switching to LWP 21127]
0x000055555562bf9c in runtime.argv_index (argv=0x5555557f1060 <usbkvm::s_device_name>, i=-134226015) at /usr/lib/go/src/runtime/runtime1.go:63
63		return *(**byte)(add(unsafe.Pointer(argv), uintptr(i)*goarch.PtrSize))
(gdb) bt
#0  0x000055555562bf9c in runtime.argv_index (argv=0x5555557f1060 <usbkvm::s_device_name>, i=-134226015) at /usr/lib/go/src/runtime/runtime1.go:63
#1  runtime.sysargs (argc=-134226016, argv=0x5555557f1060 <usbkvm::s_device_name>) at /usr/lib/go/src/runtime/os_linux.go:243
#2  0x000055555564259f in runtime.args (c=-134226016, v=0x5555557f1060 <usbkvm::s_device_name>) at /usr/lib/go/src/runtime/runtime1.go:69
#3  0x0000555555669ca5 in runtime.args (c=-134226016, v=0x5555557f1060 <usbkvm::s_device_name>) at <autogenerated>:1
#4  0x0000555555665336 in runtime.rt0_go () at /usr/lib/go/src/runtime/asm_amd64.s:347
#5  0x00000000f7ffdfa0 in ??? ()
#6  0x00005555557f1060 in ??? ()
#7  0x0000000000000000 in ??? ()
```

doesn't seem to be this repository, rather something in ms-tools - but that seemed to compile and run OK when I tried it afterwards. So it's likely a CGO issue... not sure how to approach this :(

OS: Alpine Linux edge
Device: `534d:2109 MacroSilicon USBKVM` (although the behavior is exactly the same without it plugged in)

carrotIndustries, 2025-03-14:
I don't know much about go either, barely managed to write the wrappers to use ms-tools from C++.

Some googling surfaced https://github.com/d99kris/nchat/issues/204#issuecomment-2002282032 linking to https://github.com/golang/go/issues/13492 Which points to cgo not being compatible with musl

This mentions dynamic linking, though I'm building the go module as a static library.

sdomi, 2025-03-14:
welp. i suppose that my two USBKVMs are gonna stay dumb video grabbers for now :( thanks for looking into it, anyways

kleinesfilmroellchen, 2025-03-19:
Looks like a fix for this was worked on in Go upstream, but has been sitting around without attention since September. https://go-review.googlesource.com/c/go/+/610837

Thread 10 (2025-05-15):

Arrow keys don't work on Windows

nzbr, 2025-05-15:
When connecting to the USBKVM from a computer running Windows, the arrow keys don't work. I can confirm that this is not an issue with the USBKVM itself, but the client software, because they work just fine on Linux
There may be other keys which aren't captured properly, but I haven't tested much beyond the UEFI config utility of the connected computer yet. So far I can confirm that regular letters, Enter and ESC do seem to work fine

carrotIndustries, 2025-05-15:
Ah yes, can you try the `scancode-win32` branch and see if this fixes it?

nzbr, 2025-05-16:
That seems to work!

carrotIndustries, 2025-05-16:
Thanks, made a new release to address this bug.

Closed 2025-05-16.

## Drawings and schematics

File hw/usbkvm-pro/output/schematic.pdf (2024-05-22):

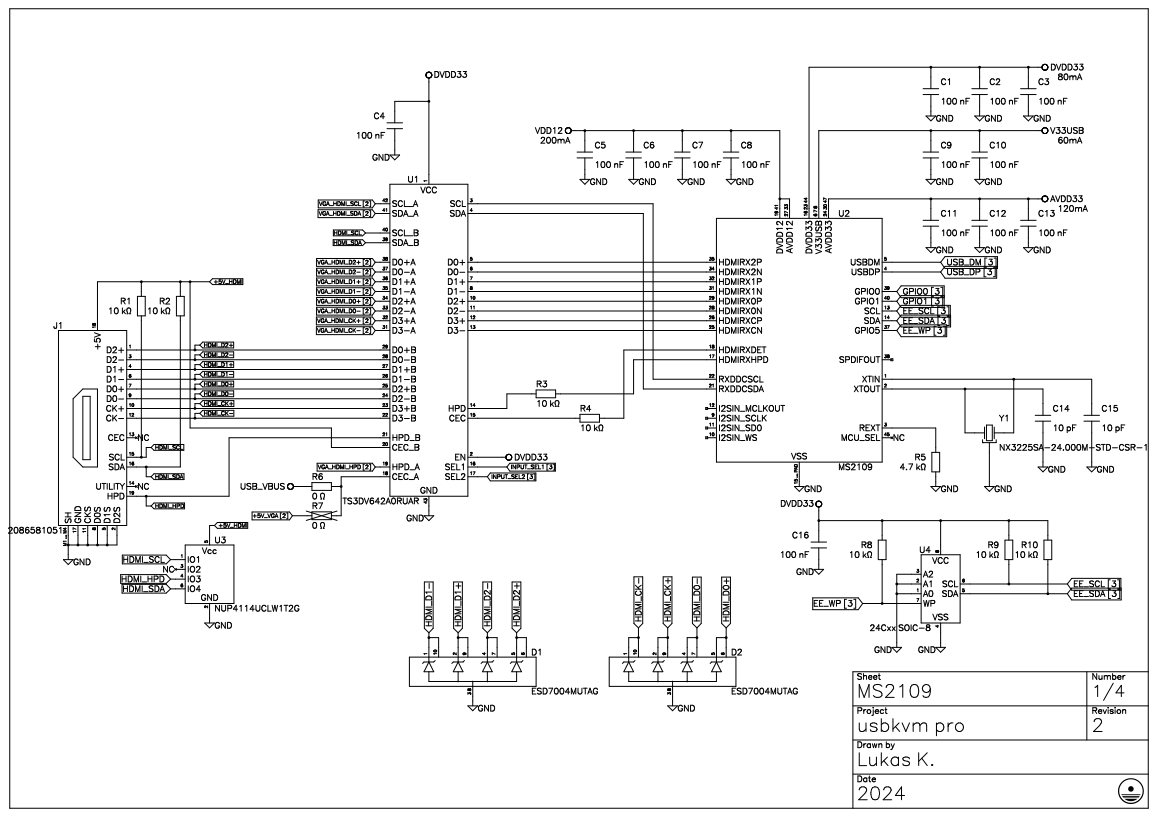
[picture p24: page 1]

MS2109
usbkvm pro | 2

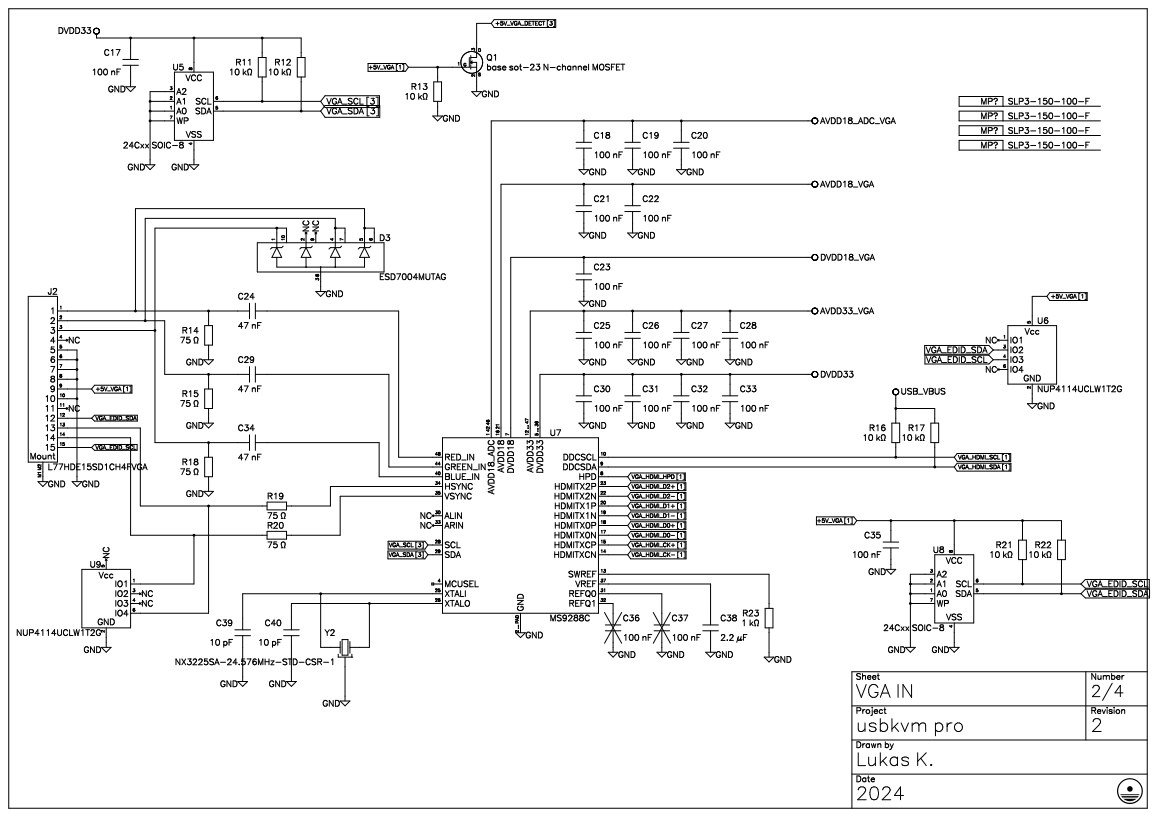
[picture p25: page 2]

VGA IN
usbkvm pro | 2

# SBU2 ³ NC Shield M¹ ... M⁴

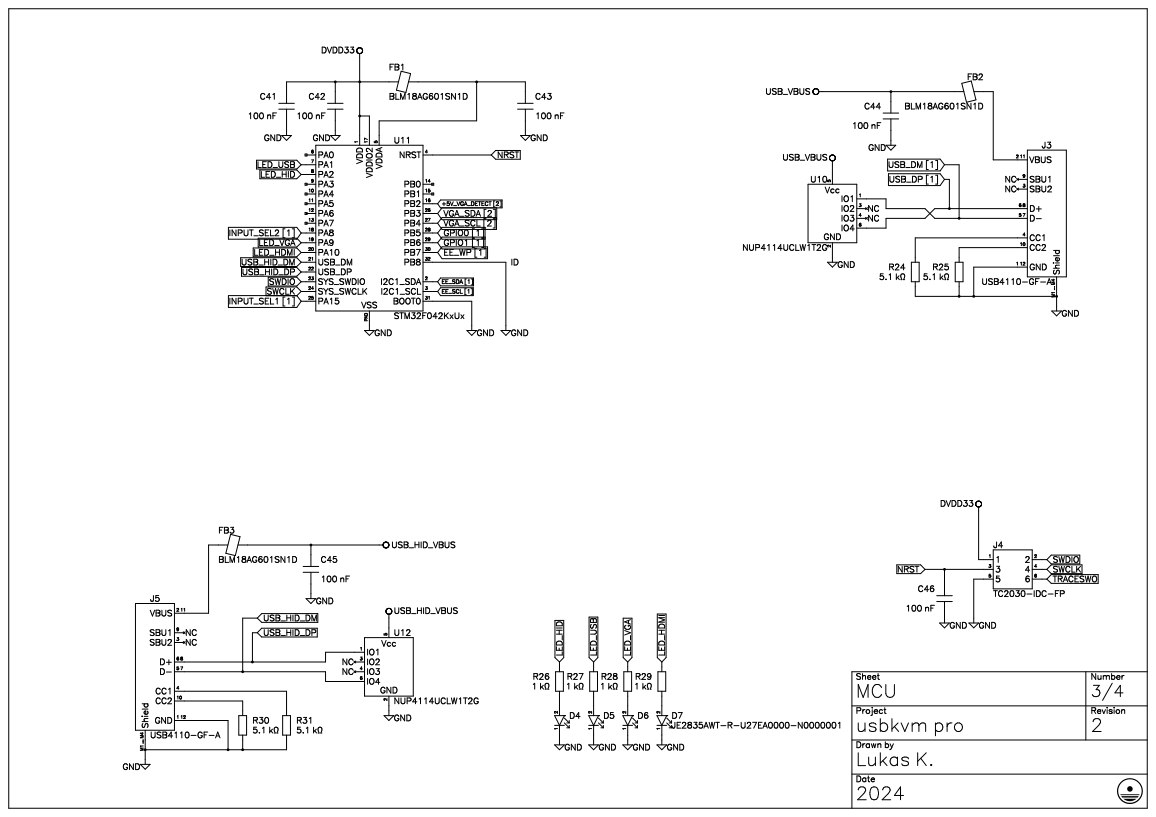
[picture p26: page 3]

MCU
usbkvm pro | 2

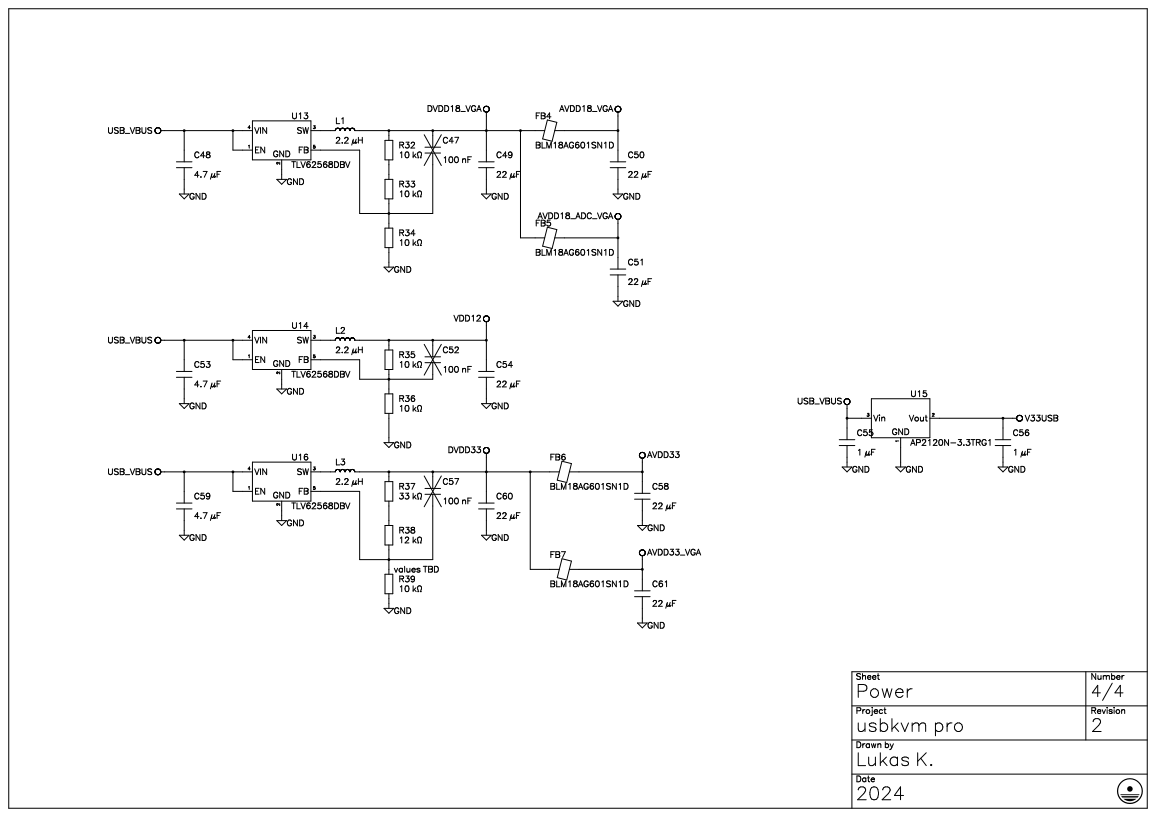
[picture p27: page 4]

Power
usbkvm pro | 2

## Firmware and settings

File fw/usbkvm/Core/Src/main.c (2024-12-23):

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
/* Includes ------------------------------------------------------------------*/
#include "main.h"

/* USER CODE BEGIN Includes */
#include "tusb.h"
#include "usb_descriptors.h"
#include "../../../common/Inc/i2c_comm.h"
#include "../../../common/Inc/usbkvm_common.h"
#include "../../../common/Inc/flash_header.h"
#include "stm32f0xx_ll_system.h"
/* USER CODE END Includes */

I2C_HandleTypeDef hi2c1;

PCD_HandleTypeDef hpcd_USB_FS;

void SystemClock_Config(void);
static void MX_GPIO_Init(void);
static void MX_I2C1_Init(void);
static void MX_USB_PCD_Init(void);
/* USER CODE BEGIN 0 */

const volatile flash_header_t g_flash_header __attribute__ ((section (".flash_hdr"))) = {.magic = 0x1337, .app_version = I2C_APP_VERSION};
volatile uint32_t g_vector_table[48] __attribute__((section(".ram_vector_table")));


static uint8_t read_vga_connected()
{
  return !HAL_GPIO_ReadPin(P5V_VGA_DETECT_GPIO_Port, P5V_VGA_DETECT_Pin);
}

// Invoked when received GET_REPORT control request
// Application must fill buffer report's content and return its length.
// Return zero will cause the stack to STALL request
uint16_t tud_hid_get_report_cb(uint8_t instance, uint8_t report_id,
                               hid_report_type_t report_type, uint8_t *buffer,
                               uint16_t reqlen) {
  // TODO not Implemented
  (void)instance;
  (void)report_id;
  (void)report_type;
  (void)buffer;
  (void)reqlen;

  return 0;
}

// Invoked when received SET_REPORT control request or
// received data on OUT endpoint ( Report ID = 0, Type = 0 )
void tud_hid_set_report_cb(uint8_t instance, uint8_t report_id,
                           hid_report_type_t report_type, uint8_t const *buffer,
                           uint16_t bufsize) {}

void tud_hid_set_protocol_cb(uint8_t instance, uint8_t protocol) {
  (void)instance;
  (void)protocol;

  // nothing to do since we use the same compatible boot report for both Boot
  // and Report mode.
  // TODO set a indicator for user
}

typedef struct TU_ATTR_PACKED {
  uint8_t buttons;  /**< buttons mask for currently pressed buttons in the mouse. */
  int16_t x;    /**< Current delta x movement of the mouse. */
  int16_t y;    /**< Current delta y movement on the mouse. */
  int8_t wheel; /**< Current delta wheel movement on the mouse. */
  int8_t pan;   // using AC Pan
} hid_mouse_abs_report_t;

static const uint32_t report_timeout = 100;

void i2c_req_handle_keyboard_report(i2c_req_keyboard_report_t *req)
{
  uint32_t ticks_start = HAL_GetTick();
  i2c_resp_buf.report.success = 1;
  while(!tud_hid_n_ready(ITF_NUM_KEYBOARD)) {
    tud_task();
    if((HAL_GetTick() - ticks_start) > report_timeout) {
      i2c_resp_buf.report.success = 0;
      break;
    }
  }
  if(i2c_resp_buf.report.success)
    tud_hid_n_keyboard_report(ITF_NUM_KEYBOARD, 0, req->mod, req->keycode);
  i2c_resp_buf.report.seq = req->seq;
}

void i2c_req_handle_mouse_report(i2c_req_mouse_report_t *req)
{
  uint32_t ticks_start = HAL_GetTick();
  i2c_resp_buf.report.success = 1;
  while(!tud_hid_n_ready(ITF_NUM_MOUSE)) {
    tud_task();
    if((HAL_GetTick() - ticks_start) > report_timeout) {
      i2c_resp_buf.report.success = 0;
      break;
    }
  }
  if(i2c_resp_buf.report.success) {
    hid_mouse_abs_report_t report = {.buttons = req->button,
                                      .x = req->x,
                                      .y = req->y,
                                      .wheel = req->v,
                                      .pan = req->h};

    tud_hid_n_report(ITF_NUM_MOUSE, 0, &report, sizeof(report));
  }
  i2c_resp_buf.report.seq = req->seq;
}

void i2c_req_handle_get_info(const i2c_req_unknown_t *unk)
{
  i2c_resp_buf.info.version = I2C_APP_VERSION;
  i2c_resp_buf.info.model = get_hw_model();
  i2c_resp_buf.info.seq = unk->seq;
}

void i2c_req_handle_get_status(const i2c_req_unknown_t *unk)
{
  uint8_t status = 0;
  if(read_vga_connected())
    status |= I2C_STATUS_VGA_CONNECTED;
  i2c_resp_buf.status.status = status;
  i2c_resp_buf.status.seq = unk->seq;
}

static i2c_req_set_led_t led_override;

static uint8_t get_led(uint8_t led, uint8_t orig_state) {
  if (led_override.mask & led)
    return led_override.stat & led;
  return orig_state;
}

void i2c_req_handle_set_led(const i2c_req_set_led_t *led) {
  led_override = *led;
}

void i2c_req_handle_get_unique_id(const i2c_req_unknown_t *unk) {
  memcpy(i2c_resp_buf.unique_id.uid, (uint32_t*)UID_BASE, sizeof(i2c_resp_buf.unique_id.uid));
  i2c_resp_buf.unique_id.seq = unk->seq;
}

static uint16_t led_usb_counter = 0;

void update_leds()
{
  HAL_GPIO_WritePin(LED_USB_GPIO_Port, LED_USB_Pin,
                    get_led(I2C_LED_USB, led_usb_counter != 0));
  if (led_usb_counter)
    led_usb_counter--;
}

static void i2c_req_dispatch(i2c_req_all_t *req)
{
  switch(req->unk.type) {
    case I2C_REQ_KEYBOARD_REPORT:
      led_usb_counter = 50;
      i2c_req_handle_keyboard_report(&req->kbd);
      break;
    case I2C_REQ_MOUSE_REPORT:
      led_usb_counter = 50;
      i2c_req_handle_mouse_report(&req->mouse);
      break;
    case I2C_REQ_COM_GET_INFO:
      i2c_req_handle_get_info(&req->unk);
      break;
    case I2C_REQ_GET_STATUS:
      i2c_req_handle_get_status(&req->unk);
      break;
    case I2C_REQ_SET_LED:
      i2c_req_handle_set_led(&req->set_led);
      break;
    case I2C_REQ_GET_UNIQUE_ID:
      i2c_req_handle_get_unique_id(&req->unk);
      break;
    case I2C_REQ_ENTER_BOOTLOADER:
      NVIC_SystemReset();
      break;
  }
}

/* USER CODE END 0 */

/**
  * @brief  The application entry point.
  * @retval int
  */
int main(void)
{
  /* USER CODE BEGIN 1 */
  for(int i = 0; i < 48; i++)
  {
    g_vector_table[i] = *(volatile uint32_t*)(0x8000000+0x2000+0x20 + (i<<2));
  }

  /* Enable the SYSCFG peripheral clock*/
  __HAL_RCC_SYSCFG_CLK_ENABLE();
  /* Remap SRAM at 0x00000000 */
  LL_SYSCFG_SetRemapMemory(LL_SYSCFG_REMAP_SRAM);
  /* USER CODE END 1 */

  /* MCU Configuration--------------------------------------------------------*/

  /* Reset of all peripherals, Initializes the Flash interface and the Systick. */
  HAL_Init();

  /* Configure the system clock */
  SystemClock_Config();

  /* Initialize all configured peripherals */
  MX_GPIO_Init();
  MX_I2C1_Init();
  MX_USB_PCD_Init();
  /* USER CODE BEGIN 2 */
  
  update_hw_model();
  
  if(get_hw_model() == I2C_MODEL_USBKVM_PRO) {
    HAL_GPIO_WritePin(INPUT_SEL1_GPIO_Port, INPUT_SEL1_Pin, GPIO_PIN_SET);
    HAL_GPIO_WritePin(INPUT_SEL2_GPIO_Port, INPUT_SEL2_Pin, GPIO_PIN_RESET);
  }

  tusb_init();
  hi2c1.Instance->TXDR = 0x83;
  
  HAL_I2C_EnableListen_IT(&hi2c1);
  led_usb_counter = 1000;

  /* USER CODE END 2 */

  /* Infinite loop */
  /* USER CODE BEGIN WHILE */
  while (1) {
    tud_task();
    HAL_GPIO_WritePin(LED_HID_GPIO_Port, LED_HID_Pin,
                      get_led(I2C_LED_HID, tud_hid_n_ready(ITF_NUM_KEYBOARD)));
    HAL_GPIO_WritePin(LED_HDMI_GPIO_Port, LED_HDMI_Pin,
                      get_led(I2C_LED_HDMI, 0));

    if (get_hw_model() == I2C_MODEL_USBKVM_PRO) {
      uint8_t has_vga = read_vga_connected();
      HAL_GPIO_WritePin(LED_VGA_GPIO_Port, LED_VGA_Pin, has_vga);
      HAL_GPIO_WritePin(INPUT_SEL2_GPIO_Port, INPUT_SEL2_Pin, !has_vga);
    }
    
    i2c_req_all_t req;
    if(i2c_read_req(&req)) {
      i2c_req_dispatch(&req);
    }
    /* USER CODE END WHILE */

    /* USER CODE BEGIN 3 */
  }
  /* USER CODE END 3 */
}

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


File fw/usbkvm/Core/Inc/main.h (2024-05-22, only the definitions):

#define LED_USB_Pin GPIO_PIN_1
#define LED_USB_GPIO_Port GPIOA
#define LED_HID_Pin GPIO_PIN_2
#define LED_HID_GPIO_Port GPIOA
#define P5V_VGA_DETECT_Pin GPIO_PIN_2
#define P5V_VGA_DETECT_GPIO_Port GPIOB
#define INPUT_SEL2_Pin GPIO_PIN_8
#define INPUT_SEL2_GPIO_Port GPIOA
#define LED_VGA_Pin GPIO_PIN_9
#define LED_VGA_GPIO_Port GPIOA
#define LED_HDMI_Pin GPIO_PIN_10
#define LED_HDMI_GPIO_Port GPIOA
#define INPUT_SEL1_Pin GPIO_PIN_15
#define INPUT_SEL1_GPIO_Port GPIOA
#define VGA_SDA_Pin GPIO_PIN_3
#define VGA_SDA_GPIO_Port GPIOB
#define VGA_SCL_Pin GPIO_PIN_4
#define VGA_SCL_GPIO_Port GPIOB
#define HDMI_GPIO0_Pin GPIO_PIN_5
#define HDMI_GPIO0_GPIO_Port GPIOB
#define HDMI_GPIO1_Pin GPIO_PIN_6
#define HDMI_GPIO1_GPIO_Port GPIOB
#define EE_WP_Pin GPIO_PIN_7
#define EE_WP_GPIO_Port GPIOB
#define HW_DETECT_Pin GPIO_PIN_8
#define HW_DETECT_GPIO_Port GPIOB

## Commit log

2024-05-09 check if device name starts with USBKVM
    sometimes, it's called 'USBKVM: USBKVM'
2024-05-09 also check for other device property
2024-05-22 add usbkvm pro
    [2086581051.stp, BIVAR__INC_SLP3-150-100-F.step, C_0402_1005Metric.step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]
2024-12-15 firmware/app: make i2c communication structs harder to use incorrectly
2024-12-17 app id: make net.carrotindustries all lower case
    to comply with flathub guidelines
2024-12-18 handle reconnecting video device
2024-12-18 don't crash when disconnecting USBKVM
    [mshal.cpp]
2024-12-22 add application class
    - move device detection there
    - to support multiple USBKVMs
2024-12-22 improve error handling
    for insufficient permissions
    and improve READMEs
    [usbkvm_application.cpp]
2024-12-23 add devices window
2024-12-23 don't immediately update capture resolution
    this sometimes freezes the video feed
    and make sure timers track the window lifetime
2024-12-31 device detection: only use v4l2 sources
    on systems with libcamera installed, the v4l2 sources are hidden. the
    libcamera device info isn't usable for anything at all. including all
    devices causes the v4l2 sources to appear.
    There used to be code to handle extracting the relevant device info from
    pipewire sources, but this would have caused the same device to be
    detected twice, so remove that code.
2024-12-31 poll for HID device
    so that it appears faster
2025-01-04 add force-firmware-update command line option
    for recovering from broken firmware
    [usbkvm_application.cpp]
2025-01-04 fix F10
    got broken in 2ba282a1948892b017b1a3f1ab06acf043539f8f
    [usbkvm_application.cpp]
2025-01-04 input: use scancodes rather than X11 keysyms
    so that it works for host keyboard layouts other than US
    fixes #4
    [get_keymap.cpp]
2025-05-25 update MS2109 EEPROM for new EDID
    with a default resolution of 1024x768
    this improves compatbility with some installers where the UI doesn't fit
    the default resolution of 1280x720
    [mshal.cpp]
2026-02-10 also detect video devices via pipewire
    happens in newer flatpak runtimes
2026-02-10 add i2c delay
    on windows, HID accesses seem to be faster than on windows, causing the firmware in the MS2109 capture chip to crash
    on windows, it's ensured that the time between the starts of subsequent
    I2C transfers is at least 1ms
    for debugging, this can be overriden using the command line switch
    --i2c-delay
    [mshal.cpp, usbkvm_application.cpp]

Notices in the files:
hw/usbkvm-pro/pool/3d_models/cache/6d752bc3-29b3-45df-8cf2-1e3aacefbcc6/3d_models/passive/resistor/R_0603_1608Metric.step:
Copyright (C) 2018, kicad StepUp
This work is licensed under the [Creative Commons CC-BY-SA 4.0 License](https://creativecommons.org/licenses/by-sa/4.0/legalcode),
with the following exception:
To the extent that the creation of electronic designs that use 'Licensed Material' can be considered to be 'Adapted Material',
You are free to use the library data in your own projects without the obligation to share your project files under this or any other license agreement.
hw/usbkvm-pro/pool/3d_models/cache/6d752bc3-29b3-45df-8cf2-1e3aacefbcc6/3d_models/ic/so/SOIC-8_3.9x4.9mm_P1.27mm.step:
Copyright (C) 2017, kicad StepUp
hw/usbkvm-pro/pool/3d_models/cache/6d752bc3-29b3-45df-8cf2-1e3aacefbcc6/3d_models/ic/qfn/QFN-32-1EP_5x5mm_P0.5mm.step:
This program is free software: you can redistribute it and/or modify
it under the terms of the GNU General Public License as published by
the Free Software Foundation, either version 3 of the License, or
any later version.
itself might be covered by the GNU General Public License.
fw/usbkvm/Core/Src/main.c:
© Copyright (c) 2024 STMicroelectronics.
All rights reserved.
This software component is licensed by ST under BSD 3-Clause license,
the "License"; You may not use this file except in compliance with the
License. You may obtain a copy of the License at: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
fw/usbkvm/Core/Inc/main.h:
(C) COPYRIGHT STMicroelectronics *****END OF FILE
